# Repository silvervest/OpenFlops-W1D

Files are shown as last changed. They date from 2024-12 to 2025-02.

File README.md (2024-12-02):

# OpenFlops W1D
OpenFlops is an Open Hardware Floppy Disk Drive emulator/simulator.

OpenFlops W1D is a complete modification for the original OpenFlops specifically configured for use replacing the flaky Citizen W1D floppy drives, popularly used in Compaq LTE Elite laptops.

For a lot more detail, installation and usage guides, visit https://silvestron.com/openflops-w1d/

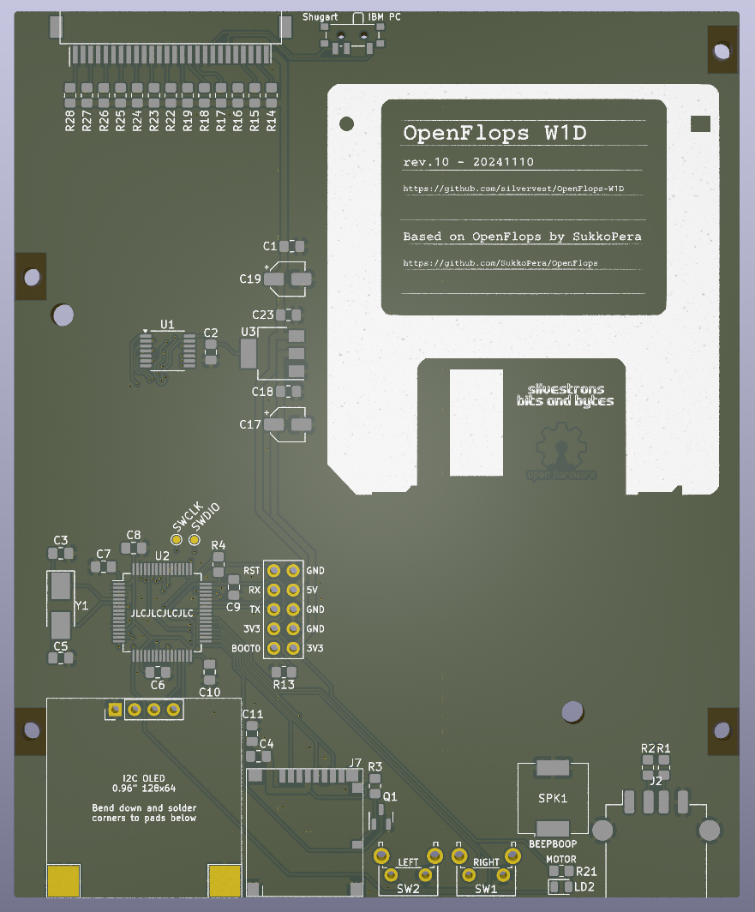
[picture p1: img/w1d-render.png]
Board


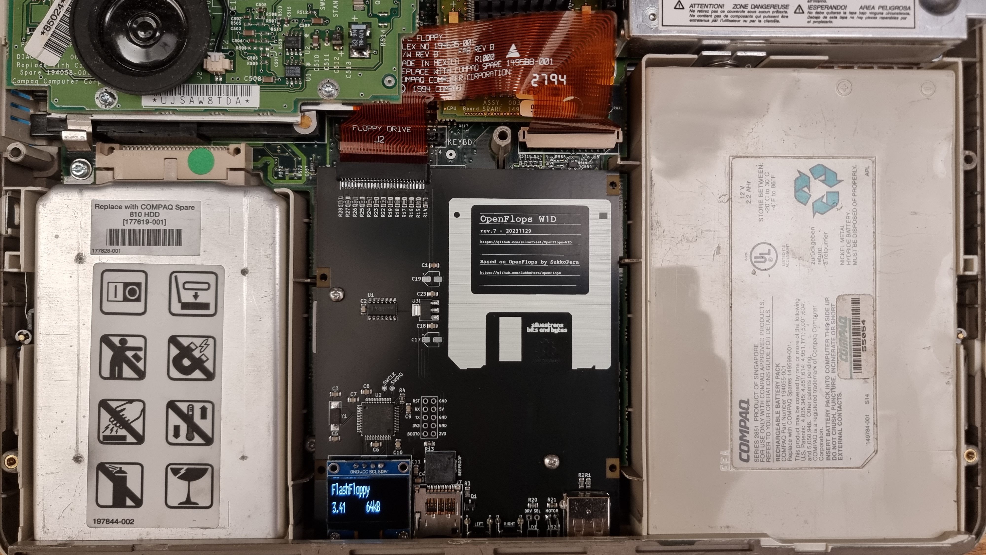
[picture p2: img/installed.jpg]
Installed


## Specifics to W1D

While this design is specifically made for the W1D when used in an LTE Elite laptop, it definitely can be used with any other floppy drive that uses the 26-pin FPC connector, it just may not fit in the same space. Heed caution.

Additionally, I made this with a few specific parts in mind - they are as follows:

* J1 - 26-pin FPC connector, part no. PCB-C5-26-SA-SMT
* J2 - USB-A port, part no. GCT USB1046
* J7 - microSD slot, part no. TF-114
* OLED - Any generic 128x64 0.96" OLED (WAVGAT on AliExpress)
* SPKR1 - Piezo buzzer, part no. CPT-9019S-SMT-TR
* SW3 - Slide switch, part no. MSK-12C02

## The rest of this README is from upstream OpenFlops!

See https://github.com/SukkoPera/OpenFlops/

### Summary
From [Wikipedia](https://en.wikipedia.org/wiki/Floppy_disk_hardware_emulator):
> Older models of computers, electronic keyboards and industrial automation often used floppy disk drives for data transfer. Older equipment may be difficult to replace or upgrade because of cost, requirement for continuous availability or unavailable upgrades. Proper operation may require operating system, software and data to be read and written from and to floppies, forcing users to maintain floppy drives on supporting systems.

> Floppy disks and floppy drives are gradually going out of production, and replacement of malfunctioning drives, and the systems hosting them, is becoming increasingly difficult. Floppy disks themselves are fragile, or may need to be replaced often. An alternative is to use a floppy disk hardware emulator, a device which appears to be a standard floppy drive to the old equipment by interfacing directly to the floppy disk controller, while storing data in another medium such as a USB thumb drive, Secure Digital card, or a shared drive on a computer network. Emulators can also be used as a higher-performance replacement for mechanical floppy disk drives. 

OpenFlops is an Open Hardware implementation of such an emulator, inspired from the ubiquitous Gotek hardware. It is designed to run the [FlashFloppy](https://github.com/keirf/FlashFloppy) firmware, which gives it several improvements over the original Gotek:
- Can be installed on [many different platforms](https://github.com/keirf/FlashFloppy/wiki/Host-Platforms)
- Directly supports a [wide range of image formats](https://github.com/keirf/FlashFloppy/wiki/Image-Formats)
- [Flexible track layout](https://github.com/keirf/FlashFloppy/wiki/Track-Layouts) for Raw Sector Images
- [Extremely configurable](https://github.com/keirf/FlashFloppy/wiki/FF.CFG-Configuration-File)
- Supports [AutoSwap](https://github.com/keirf/FF_AutoSwap) for games with a large number of disks
- Easily accessible pin headers for connection of a [i2c display](https://github.com/keirf/FlashFloppy/wiki/Hardware-Mods#lcd-display) (either OLED or LCD), [rotary encoder](https://github.com/keirf/FlashFloppy/wiki/Hardware-Mods#rotary-encoder) (including power)
- Built-in amplified speaker, or easily-accessible pin header for an external one
- USB connector can either be soldered on the board or connected to a pin header
- Connected Motor signal
- Emulates two drives at the same time (Not yet supported by the firmware, but [it will come](https://github.com/keirf/FlashFloppy/wiki/Donations))
- Has additional 3.3V, 5V and GND power pins
- And hey, it's Open Hardware!

All of this comes in the same form factor (and mounting holes) as the board installed in the original Gotek, hence it can be easily installed in any shell or enclosure designed for it.

### Assembly and Installation
Solder all components to the board. I suggest starting with the main microcontroller (U3), as it uses an LQFP package which is tricky to solder: the recommended technique is drag soldering, there are many videos about that on YouTube, so please look there for advice. I recommend soldering the bare minimum components needed for programming and then trying to flash it right away. This way you will be able to fix your soldering without too many components getting in the way, if needed. You will need a USB/TTL Serial converter for this: one with 3.3V I/O level is recommended, but a 5V one can be used, too (most pins on STM32 microcontrollers are 5V-tolerant, so don't worry, it's not a bad hack!). You shouldn't pay more than 1-2€ for it in any case, anyway. So, when you are ready:

- Solder U3, Y1, C3 and C5, then the programming header (the top one with power, BOOT0, TX, RX, etc.)
- Check for shorts on the 3.3V power lines, you can easily do this on the pads for C6-C10
- If your USB/Serial adapter has a 3.3V output, connect it to 3.3V on the power header, then connect ground, RX and TX
- If no 3.3V output is available, solder U4 and power the board through the 5V pin on the power header

Now you should be able to [program the STM32 microcontroller](https://github.com/keirf/FlashFloppy/wiki/Firmware-Programming). If you have difficultes you can try adding R10 (and C4) and maybe a few of C6-C10, but most likely the problem will be with the solder joints on U3, as soldering this kind of package manually is never easy, so please get a lens (or even better, a microscope) and double-check your job.

The serial adapter is only necessary for the first flashing. Subsequent updates [can be done easily via USB](https://github.com/keirf/FlashFloppy/wiki/Firmware-Update).

Note that most components are necessary, but there are a few you can skip if you are feeling lazy:
- If you are not interested in the head movement sound, you can skip the following components: SPK1, D2, R5, R6, Q7.
- If your LCD/OLED display already has pull-up resistors for the SDA/SCK lines (most do), you can skip R3 and R4.

### Configuration
Please refer to the FlashFloppy wiki for the [initial setup](https://github.com/keirf/FlashFloppy/wiki/Initial-Setup) and an overview of the [available configuration options](https://github.com/keirf/FlashFloppy/wiki/FF.CFG-Configuration-File).

Some options that you will want to override the default values of, in order to take advantage of all the features OpenFlops provides, are the following:
- `motor-delay`
- `rotary`
- `display-type`

### Releases
If you want to get this board produced, you are recommended to get [the latest release](https://github.com/SukkoPera/OpenFlops/releases) rather than the current git version, as the latter might be under development and is not guaranteed to be working.

Every release is accompanied by its Bill Of Materials (BOM) file and any relevant notes about it, which you are recommended to read carefully.

### License
The OpenFlops documentation, including the design itself, is copyright &copy; SukkoPera 2019-2020.

OpenFlops is Open Hardware licensed under the [CERN OHL v. 1.2](http://ohwr.org/cernohl).

You may redistribute and modify this documentation under the terms of the CERN OHL v.1.2. This documentation is distributed *as is* and WITHOUT ANY EXPRESS OR IMPLIED WARRANTIES whatsoever with respect to its functionality, operability or use, including, without limitation, any implied warranties OF MERCHANTABILITY, SATISFACTORY QUALITY, FITNESS FOR A PARTICULAR PURPOSE or infringement. We expressly disclaim any liability whatsoever for any direct, indirect, consequential, incidental or special damages, including, without limitation, lost revenues, lost profits, losses resulting from business interruption or loss of data, regardless of the form of action or legal theory under which the liability may be asserted, even if advised of the possibility or likelihood of such damages.

A copy of the full license is included in file [LICENSE.pdf](LICENSE.pdf), please refer to it for applicable conditions. In order to properly deal with its terms, please see file [LICENSE_HOWTO.pdf](LICENSE_HOWTO.pdf).

The contact points for information about manufactured Products (see section 4.2) are listed in file [PRODUCT.md](PRODUCT.md).

Any modifications made by Licensees (see section 3.4.b) shall be recorded in file [CHANGES.md](CHANGES.md).

The Documentation Location of the original project is https://github.com/SukkoPera/OpenFlops/.

### Support the Project
Since the project is open you are free to get the PCBs made by your preferred manufacturer, however in case you want to support the development, you can order them from PCBWay through this link:

PCB from PCBWay (https://www.pcbway.com/project/shareproject/OpenFlops_V1.html)

You get my gratitude and cheap, professionally-made and good quality PCBs, I get some credit that will help with this and [other projects](https://www.pcbway.com/project/member/shareproject/?bmbid=41100). You won't even have to worry about the various PCB options, it's all pre-configured for you!

Also, if you still have to register to that site, [you can use this link](https://www.pcbway.com/setinvite.aspx?inviteid=41100) to get some bonus initial credit (and yield me some more).

Again, if you want to use another manufacturer, feel free to, don't feel obligated :). But then you can buy me a coffee if you want:

<a href='https://ko-fi.com/L3L0U18L' target='_blank'>Buy Me a Coffee at ko-fi.com</a>

### Get Help
If you need help or have questions, you can join [the official Telegram group](https://t.me/joinchat/HUHdWBC9J9JnYIrvTYfZmg).

### Thanks
- H.M for publishing the [original Gotek schematics](doc/gotek_usb-fde_block-diagram.jpg)
- [keirf](https://github.com/keirf) for FlashFloppy
- Brian Allan for suggesting some improvements for the Speaker circuit
- Ray Bellis for suggesting adding pin headers for the USB port and speaker
- Mario Babeu for suggesting to line up the orientation of LD1 and LD2
- Patrick Kerkhof for sending me a lot of original Gotek housing for dimensional testing

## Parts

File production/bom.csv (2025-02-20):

Designator | Footprint | Quantity | Value | LCSC Part #
C1, C4 | 0805 | 2 | 10u | C15850
C10, C11, C18, C23, C6, C7, C8, C9 | 0805 | 8 | 100n
C17, C19 | CP_Elec_4x5.4 | 2 | 10u
C2 | 0805 | 1 | 100n | C49678
C3, C5 | 0805 | 2 | 20p | C107145
J1 | Adam_Tech_PCB-C5-26-SA-SMT_1x26_P1.00mm_Horizontal | 1 | FDD
J2 | USB_A_TE_292303-7_Horizontal | 1 | USB_A_FEMALE | C42637
J3 | PinHeader_2x05_P2.54mm_Vertical | 1 | PROG_PORT
J4 | PinHeader_1x04_P2.54mm_Vertical | 1 | OLED
J5, J6 | TestPoint_Pad_4.0x4.0mm | 2 | OLED Mount
J7 | microSD_XUNPU_TF-114 | 1 | Micro_SD_Card_Det1 | C266619
J99_2, J99 | OSHW-Logo2_9.8x8mm_Copper | 2 | OSHW_LOGO
LD2 | 0805 | 1 | LED_GREEN | C2297
Q1 | SOT-23 | 1 | 2N7002 | C8545
R1 | 0805 | 1 | 22 | C17561
R13 | 0805 | 1 | 10k
R14, R4 | 0805 | 2 | 1k | C17513
R15, R16, R17, R18, R19, R21, R22, R23, R24, R25, R26, R27, R28 | 0805 | 13 | 1k
R2 | 0805 | 1 | 22
R3 | 0805 | 1 | 10k | C17414
SPK1 | Buzzer_CUI_CPT-9019S-SMT | 1 | Speaker
SW1 | SW_Tactile_SPST_Angled_PTS645Vx83-2LFS | 1 | BT_RIGHT
SW2 | SW_Tactile_SPST_Angled_PTS645Vx83-2LFS | 1 | BT_LEFT
SW3 | SW_SPDT_PCM12 | 1 | CHG/RDY | C22435662
TP2 | TestPoint_Pad_D1.0mm | 1 | SWDIO
TP3 | TestPoint_Pad_D1.0mm | 1 | SWCLK
U1 | TSSOP-14_4.4x5mm_P0.65mm | 1 | SN74LVC07A | C7659
U2 | LQFP-64_10x10mm_P0.5mm | 1 | STM32F105RBT6 | C8349
U3 | SOT-223-3_TabPin2 | 1 | LM1117-3.3 | C6186
Y1 | Crystal_SMD_5032-2Pin_5.0x3.2mm_HandSoldering | 1 | 8 MHz | C115962

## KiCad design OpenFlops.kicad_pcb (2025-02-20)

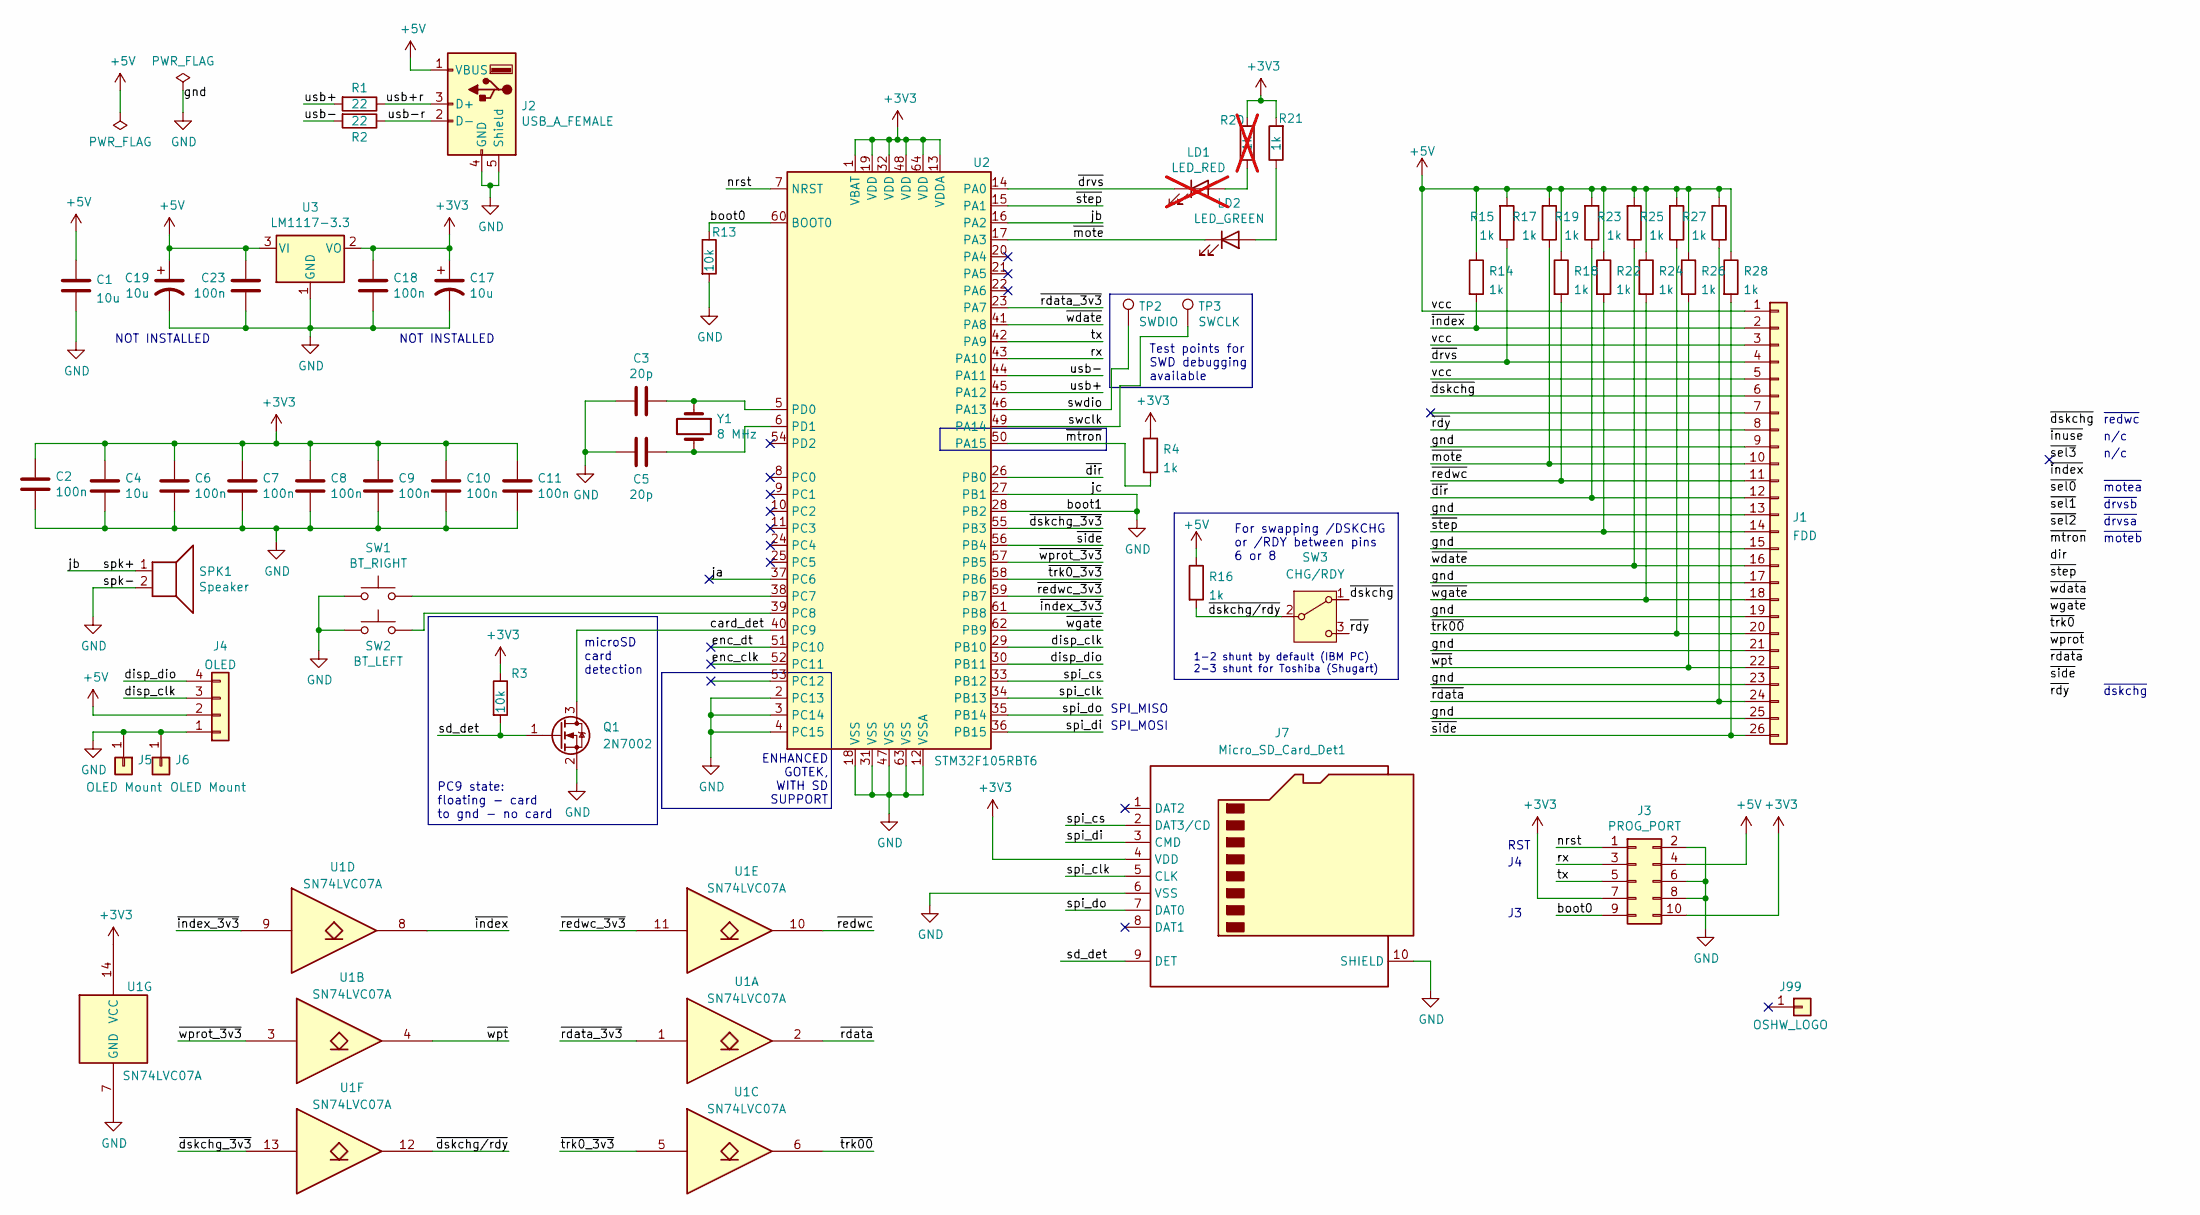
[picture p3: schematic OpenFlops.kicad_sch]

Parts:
C1, C4: 10u; C_0805_2012Metric_Pad1.18x1.45mm_HandSolder; LCSC C15850
C2, C6, C7, C8, C9, C10, C11, C18, C23: 100n; C_0805_2012Metric_Pad1.18x1.45mm_HandSolder; MFG Part Num MULTILAYER CERAMIC CAPACITORS MLCC - SM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; JLCPCB PN CC0805KRX7R9BB104
C3, C5: 20p; C_0805_2012Metric_Pad1.18x1.45mm_HandSolder; MFG Part Num MULTILAYER CERAMIC CAPACITORS MLCC - SM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; JLCPCB PN CC0805KRX7R9BB221
C17, C19: 10u; CP_Elec_4x5.4
J1: FDD; Adam_Tech_PCB-C5-26-SA-SMT_1x26_P1.00mm_Horizontal; LCSC C19188849
J2: USB_A_FEMALE; USB_A_TE_292303-7_Horizontal; LCSC C2763369
J3: PROG_PORT; PinHeader_2x05_P2.54mm_Vertical
J4: OLED; PinHeader_1x04_P2.54mm_Vertical
J5, J6: OLED Mount; TestPoint_Pad_4.0x4.0mm
J7: Micro_SD_Card_Det1; microSD_XUNPU_TF-114; LCSC C266619
J99: OSHW_LOGO; OSHW-Logo2_9.8x8mm_Copper
LD1: LED_RED; LED_0805_2012Metric; not fitted
LD2: LED_GREEN; LED_0805_2012Metric; LCSC C2297
Q1: 2N7002; SOT-23; LCSC C8545
R1, R2: 22; R_0805_2012Metric_Pad1.20x1.40mm_HandSolder; MFG Part Num CHIP RESISTOR - SURFACE MOUNT 22OHMS ±1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; JLCPCB PN 0805W8F220JT5E
R3: 10k; R_0805_2012Metric_Pad1.20x1.40mm_HandSolder; LCSC C17414
R4, R14: 1k; R_0805_2012Metric_Pad1.20x1.40mm_HandSolder; LCSC C17513
R13: 10k; R_0805_2012Metric_Pad1.20x1.40mm_HandSolder
R15, R16, R17, R18, R19, R21, R22, R23, R24, R25, R26, R27, R28: 1k; R_0805_2012Metric_Pad1.20x1.40mm_HandSolder
R20: 1k; R_0805_2012Metric_Pad1.20x1.40mm_HandSolder; not fitted
SPK1: Speaker; Buzzer_CUI_CPT-9019S-SMT; LCSC C968734
SW1: BT_RIGHT; SW_Tactile_SPST_Angled_PTS645Vx83-2LFS
SW2: BT_LEFT; SW_Tactile_SPST_Angled_PTS645Vx83-2LFS; LCSC C125034
SW3: CHG/RDY; SW_SPDT_PCM12; LCSC C22435662
TP2: SWDIO; TestPoint_Pad_D1.0mm
TP3: SWCLK; TestPoint_Pad_D1.0mm
U1: SN74LVC07A; TSSOP-14_4.4x5mm_P0.65mm; LCSC C1548107
U2: STM32F105RBT6; LQFP-64_10x10mm_P0.5mm; MFG Part Num ST MICROELECTRONICS LQFP-64_10X10X05P R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; JLCPCB PN STM32F105RBT6
U3: LM1117-3.3; SOT-223-3_TabPin2; MFG Part Num LOW DROPOUT REGULATORS(LDO) POSITIVE FI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; JLCPCB PN AMS1117-3.3
Y1: 8 MHz; Crystal_SMD_5032-2Pin_5.0x3.2mm_HandSoldering; LCSC C115962

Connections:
+3V3: C2.1, C4.1, C6.1, C7.1, C8.1, C9.1, C10.1, C11.1, C17.1, C18.1, J3.7, J3.10, J7.4 (VDD), R3.1, R4.1, R20.2, R21.2, U1.14 (VCC), U2.1 (VBAT), U2.13 (VDDA), U2.19 (VDD), U2.32 (VDD), U2.48 (VDD), U2.64 (VDD), U3.2 (VO)
+5V: C1.1, C19.1, C23.1, J1.1, J1.3, J1.5, J2.1 (VBUS), J3.4, J4.2, R14.1, R15.2, R16.1, R17.2, R18.1, R19.2, R22.1, R23.2, R24.1, R25.2, R26.1, R27.2, R28.1, U3.3 (VI)
/boot0: J3.9, R13.1, U2.60 (BOOT0)
/card_det: Q1.3 (D), U2.40 (PC9)
/disp_clk: J4.3, U2.29 (PB10)
/disp_dio: J4.4, U2.30 (PB11)
/enc_clk: U2.52 (PC11)
/enc_dt: U2.51 (PC10)
/ja: U2.37 (PC6)
/jb: SPK1.1, U2.16 (PA2)
/nrst: J3.1, U2.7 (NRST)
/rx: J3.3, U2.43 (PA10)
/sd_det: J7.9 (DET), Q1.1 (G), R3.2
/spi_clk: J7.5 (CLK), U2.34 (PB13)
/spi_cs: J7.2 (DAT3/CD), U2.33 (PB12)
/spi_di: J7.3 (CMD), U2.36 (PB15)
/spi_do: J7.7 (DAT0), U2.35 (PB14)
/swclk: TP3.1, U2.49 (PA14)
/swdio: TP2.1, U2.46 (PA13)
/tx: J3.5, U2.42 (PA9)
/usb+: R1.2, U2.45 (PA12)
/usb+r: J2.3 (D+), R1.1
/usb-: R2.2, U2.44 (PA11)
/usb-r: J2.2 (D-), R2.1
/~dir: J1.12, R19.1, U2.26 (PB0)
/~drvs: J1.4, LD1.1 (K), R15.1, U2.14 (PA0)
/~dskchg_3v3: U1.13, U2.55 (PB3)
/~dskchg/rdy: R16.2, SW3.2 (B), U1.12
/~dskchg: J1.6, SW3.1 (A)
/~index_3v3: U1.9, U2.61 (PB8)
/~index: J1.2, R14.2, U1.8
/~mote: J1.10, LD2.1 (K), R17.1, U2.17 (PA3)
/~mtron: R4.2, U2.50 (PA15)
/~rdata_3v3: U1.1, U2.23 (PA7)
/~rdata: J1.24, R27.1, U1.2
/~rdy: J1.8, SW3.3 (C)
/~redwc_3v3: U1.11, U2.59 (PB7)
/~redwc: J1.11, R18.2, U1.10
/~side: J1.26, R28.2, U2.56 (PB4)
/~step: J1.14, R22.2, U2.15 (PA1)
/~trk0_3v3: U1.5, U2.58 (PB6)
/~trk00: J1.20, R25.1, U1.6
/~wdate: J1.16, R23.1, U2.41 (PA8)
/~wgate: J1.18, R24.2, U2.62 (PB9)
/~wprot_3v3: U1.3, U2.57 (PB5)
/~wpt: J1.22, R26.2, U1.4
GND: C1.2, C2.2, C3.2, C4.2, C5.2, C6.2, C7.2, C8.2, C9.2, C10.2, C11.2, C17.2, C18.2, C19.2, C23.2, J1.9, J1.13, J1.15, J1.17, J1.19, J1.21, J1.23, J1.25, J2.4 (GND), J2.5 (Shield), J3.2, J3.6, J3.8, J4.1, J5.1, J6.1, J7.6 (VSS), J7.10 (SHIELD), Q1.2 (S), R13.2, SPK1.2, SW1.1, SW2.1, U1.7 (GND), U2.2 (PC13), U2.3 (PC14), U2.4 (PC15), U2.12 (VSSA), U2.18 (VSS), U2.27 (PB1), U2.28 (PB2), U2.31 (VSS), U2.47 (VSS), U2.63 (VSS), U3.1 (GND)
unnamed: LD1.2 (A), R20.1
unnamed: LD2.2 (A), R21.1
unnamed: SW1.2, U2.38 (PC7)
unnamed: SW2.2, U2.39 (PC8)
unnamed: C3.1, U2.5 (PD0), Y1.1
unnamed: C5.1, U2.6 (PD1), Y1.2

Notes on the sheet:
~{dskchg}
n/c
~{drvsa}
RST
ENHANCED GOTEK, WITH SD SUPPORT
microSD card detection
PC9 state: floating - card to gnd - no card
SPI_MISO
SPI_MOSI
~{redwc}
For swapping /DSKCHG or /RDY between pins 6 or 8
Test points for SWD debugging available
NOT INSTALLED
~{moteb}
1-2 shunt by default (IBM PC) 2-3 shunt for Toshiba (Shugart)
~{motea}
~{drvsb}

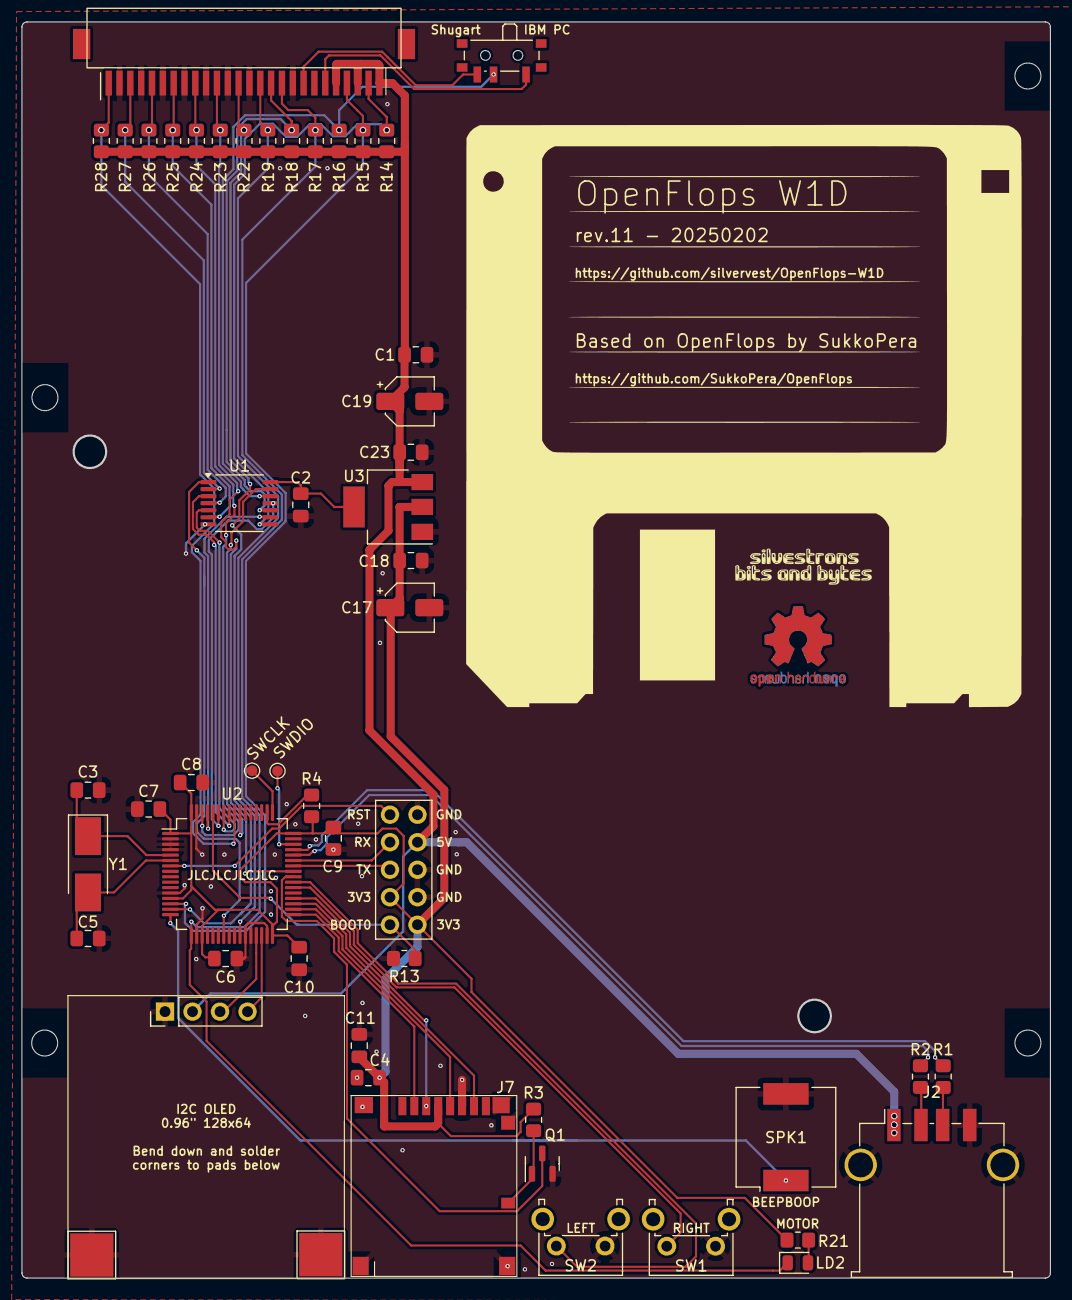
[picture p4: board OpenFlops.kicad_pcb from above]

Board: 2 copper layers, 95.0 x 116.0 mm, 55 parts (1 on the bottom side), 49 nets.

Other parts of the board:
J99#2: OSHW_LOGO; OSHW-Logo2_9.8x8mm_Copper

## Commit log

2022-03-11 updated to kicad 6; dual mount smt/tht crystal; added test points for swd
    [OpenFlops.kicad_pcb, OpenFlops.kicad_sch]
2023-04-02 update for citizen w1d
    [OpenFlops-B_Courtyard.gbr, OpenFlops-B_Cu.gbr, OpenFlops-B_Mask.gbr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]
2023-04-18 updating to fix a few cut ground traces
    [OpenFlops-B_Courtyard.gbr, OpenFlops-B_Cu.gbr, OpenFlops-B_Mask.gbr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]
2024-12-02 rev 10; more smd for more assembly
    [OpenFlops-B_Courtyard.gbr, OpenFlops-B_Cu.gbr, OpenFlops-B_Mask.gbr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]
2025-02-20 rev 11; fixed issue with usb port being too far forward
    [OpenFlops.kicad_pcb, OpenFlops.kicad_sch, bom.csv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]

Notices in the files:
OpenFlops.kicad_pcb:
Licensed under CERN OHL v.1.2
